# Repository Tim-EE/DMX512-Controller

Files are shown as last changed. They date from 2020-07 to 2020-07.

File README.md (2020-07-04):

# DMX Controller

This repository contains a hardware design for a custom DMX512 controller as well as the corresponding firmware that allows the hardware to be controlled via a serial port on a computer.

## Structure

In this repository, you'll find the following:

| Directory | Description |
| --- | --- |
| `firmware` | Contains the firmware for the DMX controller |
| `hw` | Contains the hardware designs for the DMX controller (KiCad) |
| `tools` | Contains any tools used to assist the design and use of the DMX controller |

## References

* [DMX Explained; DMX512 and RS-485 Protocol Detail for Lighting Applications](https://www.element14.com/community/groups/open-source-hardware/blog/2017/08/24/dmx-explained-dmx512-and-rs-485-protocol-detail-for-lighting-applications)
* [Wikipedia: DMX512](https://en.wikipedia.org/wiki/DMX512)

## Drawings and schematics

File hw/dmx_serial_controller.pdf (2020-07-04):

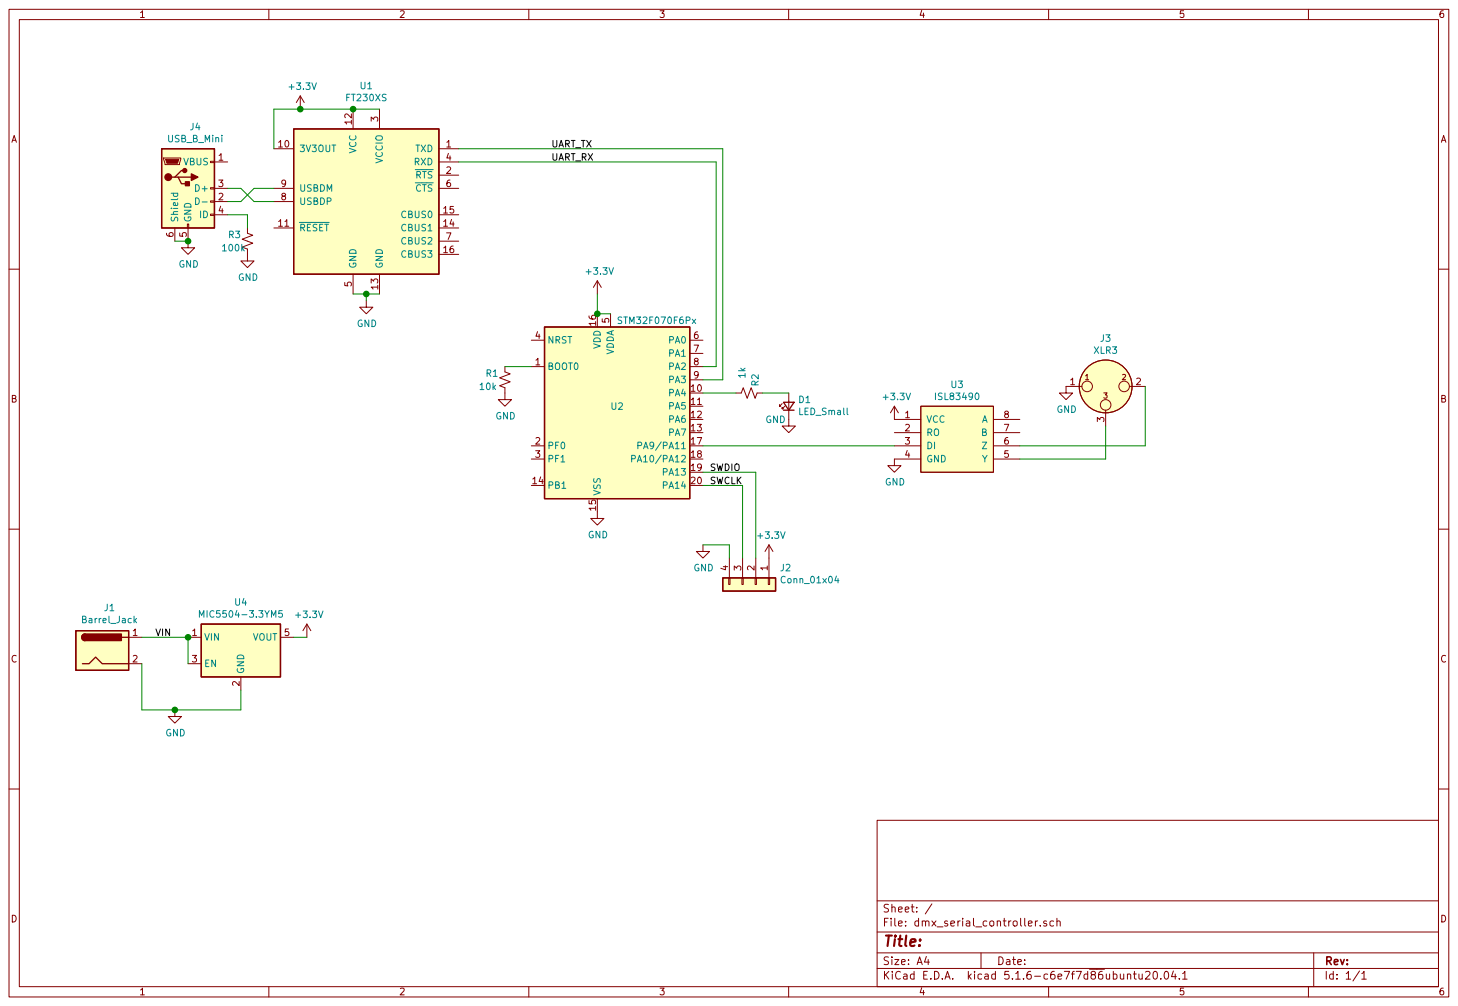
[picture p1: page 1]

5 CTS 6 CBUS2 7 USBDP 8 USBDM 9 U1 FT230XS GND GND

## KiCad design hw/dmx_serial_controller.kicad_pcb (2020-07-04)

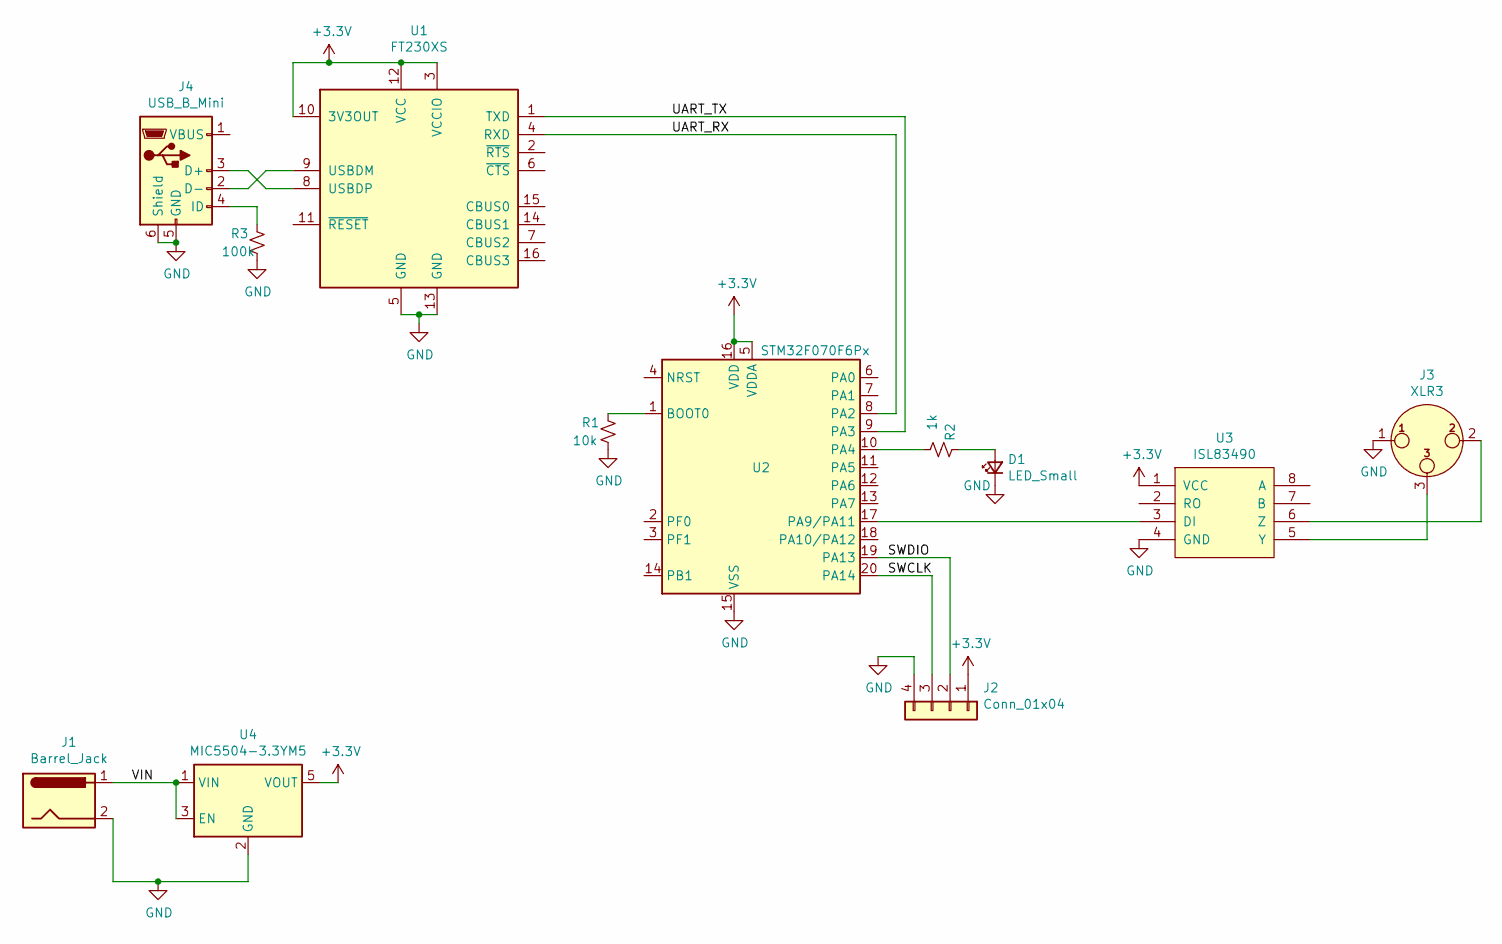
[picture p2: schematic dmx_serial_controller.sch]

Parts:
D1: LED_Small; LED_0805_HandSoldering
J1: Barrel_Jack; Pin_Header_Straight_1x02_Pitch2.54mm
J2: Conn_01x04; Pin_Header_Straight_1x04_Pitch2.54mm
J3: XLR3; Pin_Header_Straight_1x03_Pitch2.54mm
J4: USB_B_Mini; USB_Mini-B
R1: 10k; R_0805_HandSoldering
R2: 1k; R_0805_HandSoldering
R3: 100k; R_0805_HandSoldering
U1: FT230XS; SSOP-16_3.9x4.9mm_Pitch0.635mm; digikey# 768-1135-2-ND
U2: STM32F070F6Px; TSSOP-20_4.4x6.5mm_Pitch0.65mm; digikey# 497-17354-1-ND
U3: ISL83490; SOIC-8-N; digikey# ISL83490IBZ-ND
U4: MIC5504-3.3YM5; SOT-23-5; digikey# 576-4764-1-ND

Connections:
+3V3: J2.1, U1.3 (VCCIO), U1.10 (3V3OUT), U1.12 (VCC), U2.5 (VDDA), U2.16 (VDD), U3.1 (VCC), U4.5 (VOUT)
/SWCLK: J2.3, U2.20 (PA14)
/SWDIO: J2.2, U2.19 (PA13)
/UART_RX: U1.4 (RXD), U2.8 (PA2)
/UART_TX: U1.1 (TXD), U2.9 (PA3)
/VIN: J1.1, U4.1 (VIN), U4.3 (EN)
GND: D1.1 (K), J1.2, J2.4, J3.1, J4.5 (GND), J4.6 (Shield), R1.2, R3.2, U1.5 (GND), U1.13 (GND), U2.15 (VSS), U3.4 (GND), U4.2 (GND)
unnamed: D1.2 (A), R2.1
unnamed: J3.2, U3.6 (Z)
unnamed: J3.3, U3.5 (Y)
unnamed: J4.2 (D-), U1.9 (USBDM)
unnamed: J4.3 (D+), U1.8 (USBDP)
unnamed: J4.4 (ID), R3.1
unnamed: R1.1, U2.1 (BOOT0)
unnamed: R2.2, U2.10 (PA4)
unnamed: U2.17 (PA9/PA11), U3.3 (DI)

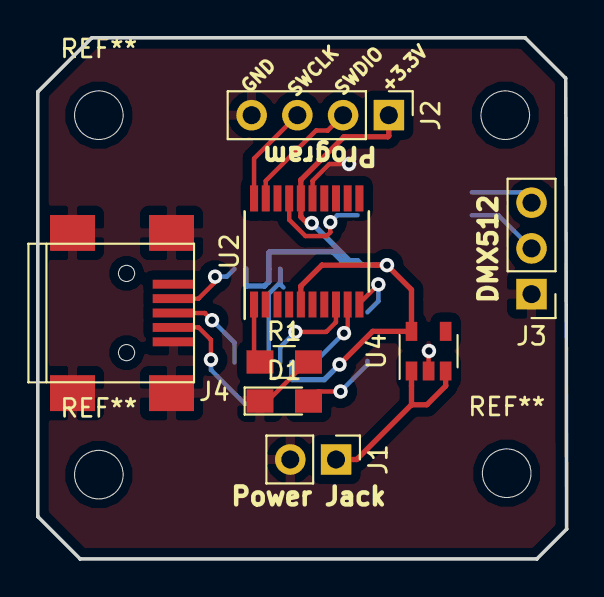
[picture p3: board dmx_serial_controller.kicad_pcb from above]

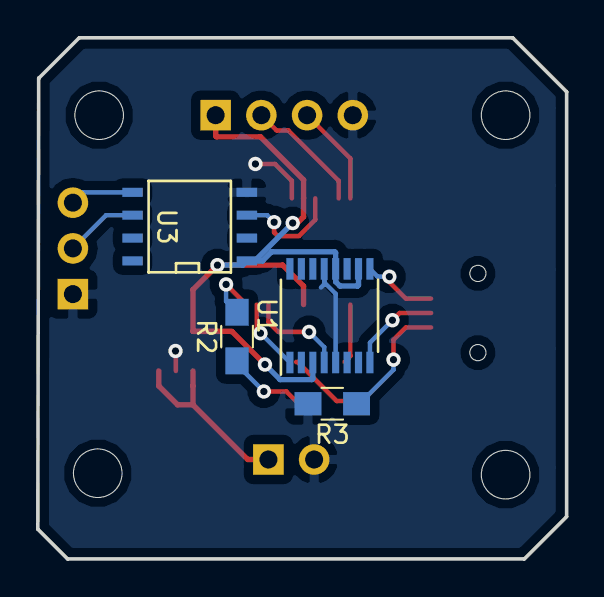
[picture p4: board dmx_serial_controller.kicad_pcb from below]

Board: 2 copper layers, 29.4 x 29.0 mm, 12 parts (4 on the bottom side), 16 nets.

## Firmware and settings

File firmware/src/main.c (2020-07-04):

#include <stdio.h>
#include <stdlib.h>
#include <stdint.h>
#include "stm32f0xx.h"
#include "stm32f0xx_usart.h"

/*============== CONST DEFINES ==============*/
#define COMMAND_UPDATE_BUFFER_SIZE 513
#define DMX_BUFFER_SIZE 513
#define RUN_LED     (1 << 0)
#define USART1_DE   (1 << 10) // PA10
#define UART_PACKET_START (0x7E)
#define UART_PACKET_END   (0xE7)

/*============== MACRO DEFINES ==============*/
#define ToggleRunLed() GPIOA->ODR ^= RUN_LED
#define SetDmxOutputToUartMode() GPIOA->MODER |= (1 << 19)
#define SetDmxOutputToGpioMode() GPIOA->MODER &= ~(3 << 18)
#define Timer14Wait_usec(usec) do { \
    TIM14->SR &= ~TIM_SR_UIF; \
    TIM14->ARR = usec; \
    TIM14->CNT = 0; \
    TIM14->CR1 |= TIM_CR1_CEN; \
    while (!(TIM14->SR & TIM_SR_UIF)); \
    TIM14->CR1 &= ~TIM_CR1_CEN; \
    } while(0)
#define DmxTransmit(data) do { \
    USART1->TDR = data; \
    while(!(USART1->ISR & (USART_ISR_TC))); \
    } while(0)


/**
 * This is used to store an array index and value for the DMX transmit array.
 */
typedef struct
{
    uint_fast16_t index;
    uint_fast8_t value;
} ValuePair;

volatile uint8_t dmx_data[DMX_BUFFER_SIZE];
volatile ValuePair updateBuffer[COMMAND_UPDATE_BUFFER_SIZE];
volatile uint_fast16_t updateBuffer_i = 0;
volatile uint_fast8_t dmxSent;
volatile uint_fast8_t dmxDataUpdateReady;


void initialize();

/**
 * The main program function
 */
int main()
{
    // initialize the hardware
    initialize();

    // initialize DMX512 universe to output 0s, any other default values should be handled here
    for (uint_fast16_t i = 1; i < sizeof(dmx_data); i++)
    {
        dmx_data[i] = 0;
    }

    // application main loop
    while (1)
    {
        // update the DMX buffer if there is data in the RX buffer
        if (dmxDataUpdateReady != 0)
        {
            // update the DMX buffer data
            for (uint_fast16_t i = 0; i < updateBuffer_i; i++)
            {
                if (updateBuffer[i].index < DMX_BUFFER_SIZE && updateBuffer[i].value < 256)
                {
                    dmx_data[updateBuffer[i].index] = updateBuffer[i].value;
                }
            }
            updateBuffer_i = 0;
            dmxDataUpdateReady = 0;
        }

        // DMX send period done
        if (dmxSent)
        {
            dmxSent = 0;

            // toggle run led to denote DMX packet sent
            ToggleRunLed();
        }
    }
    return 0;
}

/*
 * Initilize the peripheral configurations.
 */
void initialize()
{
    // Step 1: Enable the various hardware devices needed for the application.

    // enable GPIOA
    RCC_AHBPeriphClockCmd(RCC_AHBPeriph_GPIOA, ENABLE);

    // enable USARTs
    RCC_APB2PeriphClockCmd(RCC_APB2ENR_USART1EN, ENABLE);
    RCC_APB1PeriphClockCmd(RCC_APB1ENR_USART2EN, ENABLE);

    // enable TIM14
    RCC_APB1PeriphClockCmd(RCC_APB1ENR_TIM14EN, ENABLE);

    // enable TIM3
    RCC_APB1PeriphClockCmd(RCC_APB1ENR_TIM3EN, ENABLE);

    // Set the pin configurations for all required pins.
    // configure USART1 pins: TX in alternate function push pull
    GPIO_InitTypeDef pinCfg;
    pinCfg.GPIO_Mode  = GPIO_Mode_AF;
    pinCfg.GPIO_Pin   = GPIO_Pin_9;
    pinCfg.GPIO_PuPd  = GPIO_PuPd_NOPULL;
    pinCfg.GPIO_Speed = GPIO_Speed_50MHz;
    pinCfg.GPIO_OType = GPIO_OType_PP;
    GPIO_Init(GPIOA, &pinCfg);
    GPIOA -> BRR = (1<<9);
    GPIOA -> AFR[1] |= (1<<4);

    // configure LED pin
    pinCfg.GPIO_Mode  = GPIO_Mode_OUT;
    pinCfg.GPIO_OType = GPIO_OType_PP;
    pinCfg.GPIO_Pin   = RUN_LED;
    pinCfg.GPIO_PuPd  = GPIO_PuPd_NOPULL;
    pinCfg.GPIO_Speed = GPIO_Speed_50MHz;
    GPIO_Init(GPIOA, &pinCfg);


    // configure PA4 pin for output
    pinCfg.GPIO_Mode  = GPIO_Mode_OUT;
    pinCfg.GPIO_OType = GPIO_OType_PP;
    pinCfg.GPIO_Pin   = GPIO_Pin_4;
    pinCfg.GPIO_PuPd  = GPIO_PuPd_NOPULL;
    pinCfg.GPIO_Speed = GPIO_Speed_50MHz;
    GPIO_Init(GPIOA, &pinCfg);

    // configure USART1_DE pin for output
    pinCfg.GPIO_Pin   = USART1_DE;
    pinCfg.GPIO_Mode  = GPIO_Mode_OUT;
    pinCfg.GPIO_OType = GPIO_OType_PP;
    pinCfg.GPIO_PuPd  = GPIO_PuPd_NOPULL;
    pinCfg.GPIO_Speed = GPIO_Speed_50MHz;
    GPIO_Init(GPIOA, &pinCfg);

    // configure PA3 pin for input
    pinCfg.GPIO_Pin   = GPIO_Pin_3;
    pinCfg.GPIO_Mode  = GPIO_Mode_AF;
    pinCfg.GPIO_OType = GPIO_OType_PP;
    pinCfg.GPIO_PuPd  = GPIO_PuPd_NOPULL;
    pinCfg.GPIO_Speed = GPIO_Speed_50MHz;
    GPIO_Init(GPIOA, &pinCfg);

    // Configure USART1 for DMX transmissions
    USART_InitTypeDef usartCfg;
    usartCfg.USART_BaudRate = 250000;
    usartCfg.USART_HardwareFlowControl = USART_HardwareFlowControl_None;
    usartCfg.USART_Mode = USART_Mode_Tx;
    usartCfg.USART_Parity = USART_Parity_No;
    usartCfg.USART_StopBits = USART_StopBits_2;
    usartCfg.USART_WordLength = USART_WordLength_8b;
    USART_Init(USART1, &usartCfg);
    // enable USART1
    USART_Cmd(USART1, ENABLE);

    // set PA3 to AF1
    GPIO_PinAFConfig(GPIOA,GPIO_PinSource3,GPIO_AF_1);
    // configure USART2
    USART_InitTypeDef usartCfg2;
    usartCfg2.USART_BaudRate = 9600;
    usartCfg2.USART_HardwareFlowControl = USART_HardwareFlowControl_None;
    usartCfg2.USART_Mode = USART_Mode_Rx;
    usartCfg2.USART_Parity = USART_Parity_No;
    usartCfg2.USART_StopBits = USART_StopBits_1;
    usartCfg2.USART_WordLength = USART_WordLength_8b;
    USART_Init(USART2, &usartCfg2);
    // enable USART2
    USART_Cmd(USART2, ENABLE);

    // Configure timer 3 for interrupt at 25 Hz = send DMX frame at 25Hz
    // configure TIM3
    TIM3->PSC  = 7999; // prescaler of 8000
    TIM3->ARR  = 39; // period of 40 for 25Hz
    TIM3->EGR  = 1; // only set update generation
    TIM3->DIER = 1; // only enable update interrupt
    TIM3->CR1  = 1; // only set counter enable

    // set timer 14's prescaler to 7+1=8
    TIM14->PSC = 7;

    // Setup interrrupt configurations
    // turn on the UART2 interrupt
    USART2-> CR1 |= USART_CR1_RE;
    USART2-> CR1 |= USART_CR1_RXNEIE;

    // enable USART2 interrupt and set priority
    NVIC_EnableIRQ(USART2_IRQn);
    NVIC_SetPriority(USART2_IRQn, 4);

    // enable TIM3 interrupt and set priority
    NVIC_SetPriority(TIM3_IRQn, 2);
    NVIC_EnableIRQ(TIM3_IRQn);
}

/**
 * UART 2 Interrupt Service Routine
 * This function receives the UART data from the computer, gathers the data,
 * and sets the dmxDataUpdateReady flag.
 */
void USART2_IRQHandler()
{
    static uint_fast16_t uartPacketSize;
    static uint8_t packetType = 0;
    static uint_fast8_t rxPacketState = 0;
    uint8_t rxData = 0;
    // read the UART2 data into the receive buffer
    // rxBuffer[rxBuffer_i] = USART2-> RDR;
    rxData = USART2-> RDR;

    switch(rxPacketState)
    {
        case 0: // packet header
        {
            // ignore everything but packet start value
            if (rxData == UART_PACKET_START)
            {
                rxPacketState++;
                updateBuffer_i = 0;
            }
            break;
        }
        case 1: // packet type (future use)
        {
            packetType = rxData;
            rxPacketState++;
            break;
        }
        case 2: // get the packet size LSB
        {
            uartPacketSize = rxData;
            rxPacketState++;
            break;
        }
        case 3: // get the packet size MSB
        {
            uartPacketSize += rxData << 8;
            rxPacketState++;
            break;
        }
        default: // handle other data received
        {
            if (rxPacketState == (uartPacketSize-1))
            {
                if (rxData == UART_PACKET_END)
                {
                    // message parsed, reset the receive buffer pointer
                    rxPacketState = 0;
                    // alert the main loop to update the DMX transmit buffer
                    dmxDataUpdateReady = 1;
                }
            }
            else
            {
                // store the packet data into updateBuffer - the ValuePair array
                updateBuffer[updateBuffer_i].index = rxPacketState-3;
                updateBuffer[updateBuffer_i++].value = rxData;

                rxPacketState++;
            }
            break;
        }
    }
}

/**
 * Timer 3 Interrupt Service Routine
 * This function is fired every 40ms and transmits the whole DMX buffer.
 */
void TIM3_IRQHandler()
{
    // clear the interrupt flag
    TIM3->SR &= ~0x0001;

    // bring the TX pin under GPIO control
    // this has the added effect that the pin is low
    SetDmxOutputToGpioMode();

    // wait 92 microseconds for the DMX break
    Timer14Wait_usec(92);

    // bring the TX pin under UART control
    SetDmxOutputToUartMode();

    // wait 12 microseconds for the MAB (Mark After Break)
    Timer14Wait_usec(12);

    // transmit the DMX data
    for (uint_fast16_t i = 0; i < sizeof(dmx_data); i++)
    {
        // transmit the byte with a blocking send
    	// can upgrade to DMA in the future, if desired, though this isn't needed
    	// for a simple application such as this
        DmxTransmit(dmx_data[i]);
    }

    // wait one additional character time before releasing the line
    Timer14Wait_usec(44);

    // flag DMX packet as sent
    dmxSent = 1;
}



// ----------------------------------------------------------------------------

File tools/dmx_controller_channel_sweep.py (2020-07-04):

# This file is used to command each channel on the DMX universe to blink one
# after another. This way, you can tell which light is on which channel.

from __future__ import print_function
import serial
import random
import sys
import argparse
import datetime
from time import sleep

HW_OPTIONS = {'DMX_USB_PRO','CUSTOM'}
HW_SELECTION = 'DMX_USB_PRO'

DMX_ARRAY_LENGTH = 30
dmxArray = [0] * DMX_ARRAY_LENGTH

if DMX_ARRAY_LENGTH < 25:
    print("DMX_ARRAY_LENGTH cannot be less than 25, setting to 25.")
    DMX_ARRAY_LENGTH = 25
elif DMX_ARRAY_LENGTH > 512:
    print("DMX_ARRAY_LENGTH cannot be greater than 512, setting to 512.")
    DMX_ARRAY_LENGTH = 512

# print("DMX_ARRAY_LENGTH: {:d}".format(DMX_ARRAY_LENGTH))

def MakeSerialData(channelIndex,channelValue):
    serialData = None

    if HW_SELECTION == 'DMX_USB_PRO':
        dmxArray[channelIndex-1] = channelValue
        serialDataStr = ''.join('{:02x} '.format(x) for x in dmxArray)
        lowByteLength = ''.join('{:02x} '.format(DMX_ARRAY_LENGTH % 256))
        highByteLength = ''.join('{:02x} '.format(int(DMX_ARRAY_LENGTH / 256) % 256))
        serialDataStr = '7E 06 ' + lowByteLength + highByteLength + serialDataStr + 'E7'
        print(serialDataStr)
        serialData = bytearray.fromhex(serialDataStr)
        # quit()

    elif HW_SELECTION == 'CUSTOM':
        serialDataStr = ''.join('{:02x} '.format(x) for x in [0x5B, channelIndex,channelValue, 0x5D])
        # serialData = bytearray.fromhex('5B {:x} {:x} 5D'.format(channelIndex,channelValue))
        serialData = bytearray.fromhex(serialDataStr)
        print(serialDataStr)
        # quit()

    return serialData

if __name__ == '__main__':

    parser = argparse.ArgumentParser()
    parser.add_argument("-p","--port", type=int,help="The serial COM port to use")
    parser.add_argument("-max","--max-channel-count", type=int,help="The serial COM port to use")
    # parser.add_argument("-hw","--max-channel-count", type=int,help="The serial COM port to use")
    # if sys.argv[1:]:
        # args = parser.parse_args()
    args = parser.parse_args()

    maxChannel = DMX_ARRAY_LENGTH
    if args.max_channel_count:
        maxChannel = args.max_channel_count

    # if True:
    with serial.Serial() as ser:
        # ser.baudrate = 9600
        ser.baudrate = 115200
        ser.port = 'COM{:d}'.format(args.port) # look for VCOM FT245BM device driver
        ser.timeout = 1
        ser.open()
        # Get Widget Serial Number Request (Label = 10, no data)
        # check_bytes = bytes.fromhex('5B {:x} {:x} 5D'.format(index,255))
        # check_bytes = bytearray.fromhex('5B %x %x 5D'.format(index,255))
        # print("Toggling index {:d}".format(index))

        direction = -1
        dispValue = 255
        incrementValue = 5
        incrementChannelAfterNTimes = 5
        currentChannelIndex = 1
        currentChannelIterationCount = 0

        while True:
            # check_bytes = bytes.fromhex('5B {:x} {:x} 5D'.format(currentChannelIndex,dispValue))
            serialBytes = MakeSerialData(currentChannelIndex,dispValue)
            if serialBytes != None:
                ser.write(serialBytes)

            # set new value
            if (dispValue - incrementValue < 0):
                direction = 1
                currentChannelIterationCount +=1

            elif (dispValue + incrementValue > 2**8-1):
                direction = -1


            dispValue += incrementValue * direction
            # print("dispValue: " + str(dispValue))
            # print(str([hex(x) for x in serialBytes]))

            # if HW_SELECTION != 'DMX_USB_PRO':
            sleep(0.01)

            if (currentChannelIterationCount == incrementChannelAfterNTimes):
                currentChannelIterationCount = 0
                currentChannelIndex += 1
                if (currentChannelIndex >= maxChannel):
                    currentChannelIndex = 1

                print("currentChannelIndex: " + str(currentChannelIndex))

            # quit()
